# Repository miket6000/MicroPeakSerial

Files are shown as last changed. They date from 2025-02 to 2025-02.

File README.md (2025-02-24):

# MicroPeakSerial

The MicroPeakSerial is heavily based off the design detailed here [MicroPeakSerial](https://keithp.com/blogs/MicroPeakSerial/) by Keith Packard, but in KiCad rather than geda and including a housing designed in FreeCAD.

The only real changes are to include a USB A connector instead of the micro B to remove the need for a cable and to the footprint. A USB C connector was considered, but my prefered field laptop is old enough to not have one!

It should be noted that the current housing appears to hold the MicroPeak too far above the photo transistor for it to work effectively. I'm unsure at this point if I'll adjust the housing, or make improvements to the MicroPeakSerial by AC coupling the signal and using some positive feedback in the opamp to implement a basic bistable schmidt trigger. The latter option seems the better solution but brings a little complexity in ensuring the bistable opamp always powers up in the correct state.

TBC...

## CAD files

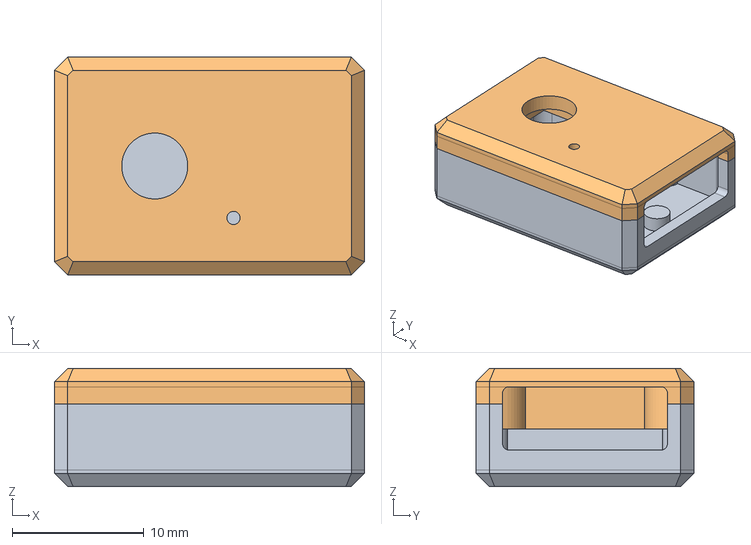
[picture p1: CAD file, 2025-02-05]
mechanical/housing.FCStd
23.5 x 16.5 x 8.97 mm
Lid

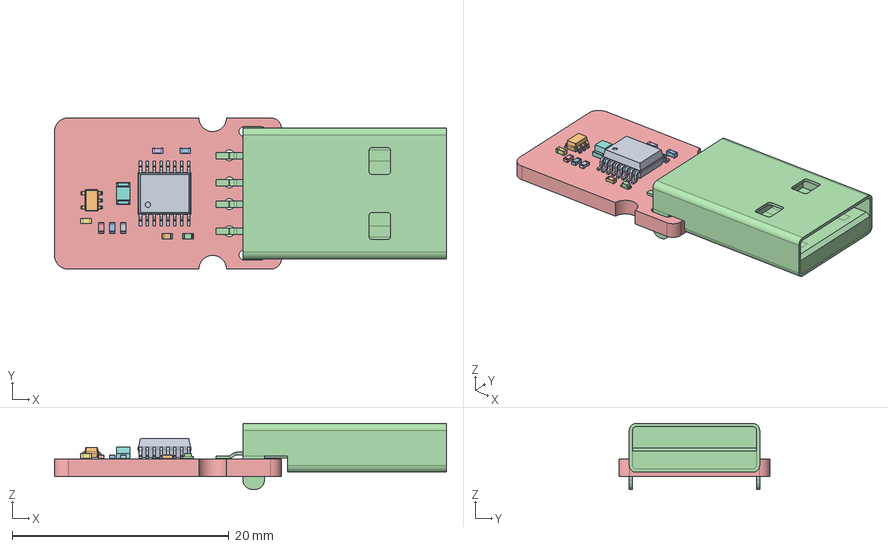
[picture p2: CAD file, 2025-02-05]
mechanical/pcba.FCStd
36.2 x 14.0 x 6.10 mm
R_0402_1005Metric
SOT_353_SC_70_5
R_0402_1005Metric002
USB_A_CNCTech_1001-011-01101_Horizontal
R_0402_1005Metric004
C_0402_1005Metric
C_0402_1005Metric002
LED_0805_2012Metric
SSOP_16_39x49mm_P0635mm
R_0402_1005Metric006
C_0402_1005Metric004
LED_0402_1005Metric
mpserial_PCB

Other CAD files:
mechanical/assembly.FCStd

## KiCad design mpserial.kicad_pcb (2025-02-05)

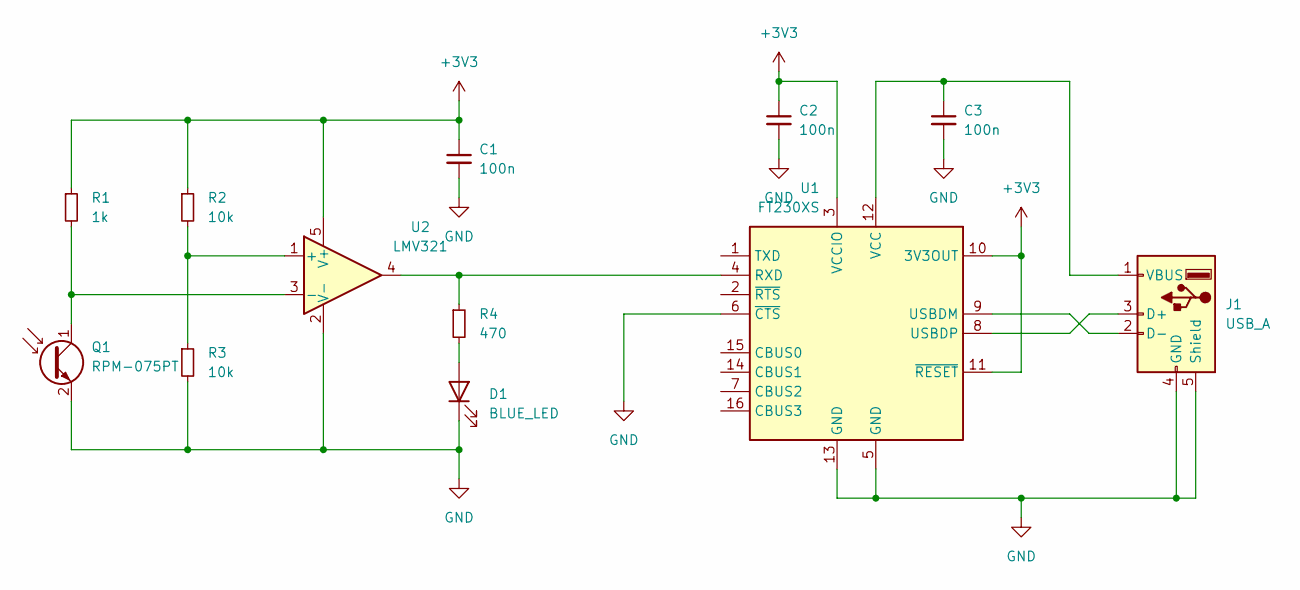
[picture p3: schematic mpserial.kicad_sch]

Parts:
C1, C2, C3: 100n; C_0402_1005Metric
D1: BLUE_LED; LED_0402_1005Metric
J1: USB_A; CONN_USB_A_MALE_HORIZONTAL_TH
Q1: RPM-075PT; LED_0805_2012Metric
R1: 1k; R_0402_1005Metric
R2, R3: 10k; R_0402_1005Metric
R4: 470; R_0402_1005Metric
U1: FT230XS; SSOP-16_3.9x4.9mm_P0.635mm
U2: LMV321; SOT-353_SC-70-5

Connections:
+3V3: C1.1, C2.1, R1.1, R2.1, U1.3 (VCCIO), U1.10 (3V3OUT), U1.11 (~RESET), U2.5 (V+)
GND: C1.2, C2.2, C3.2, D1.1 (K), J1.4 (GND), J1.5 (Shield), Q1.2 (E), R3.2, U1.5 (GND), U1.6 (~CTS), U1.13 (GND), U2.2 (V-)
unnamed: D1.2 (A), R4.2
unnamed: J1.3 (D+), U1.8 (USBDP)
unnamed: J1.2 (D-), U1.9 (USBDM)
unnamed: C3.1, J1.1 (VBUS), U1.12 (VCC)
unnamed: Q1.1 (C), R1.2, U2.3 (-)
unnamed: R4.1, U1.4 (RXD), U2.4
unnamed: R2.2, R3.1, U2.1 (+)

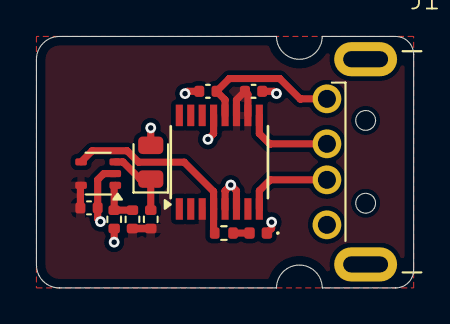
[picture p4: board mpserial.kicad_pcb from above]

Board: 2 copper layers, 21.0 x 14.0 mm, 12 parts (0 on the bottom side), 9 nets.

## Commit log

2025-01-28 initial commit.
    [assembly.FCStd, housing.FCStd, mpserial.kicad_pcb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]
2025-02-05 corrected opamp footprint and symbol names, changed USB-A connector to throughhole for cheaper assembly
    [assembly.FCStd, housing.FCStd, mpserial.kicad_pcb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]
2025-02-24 Udated README with current project status
